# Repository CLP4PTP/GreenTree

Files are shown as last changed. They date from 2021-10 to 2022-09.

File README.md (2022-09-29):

Version 1.0: costs approx. 20 euros per tree, production work per tree approx. 3-4 hours
Used parts:
https://www.reichelt.de/my/1888149
Slide switch 3 positions: https://www.muekra.de/schiebeschalter.html
Feet (4x) https://www.horter-shop.de/de/self-adhesive-foot-m3/110-self-adhesive-foot-with-internal-thread-m3-4260404260011.html
9V batteries

For flashing, 150k resistors have turned out to be the best, as they flash at a pleasantly fast frequency.

Problems:
- Base board has already been changed to V2.0 (problem with transistor voltages have been fixed, but GND and VCC had to be swapped at the foot pins of the tree for this purpose) => LEDS must be soldered "wrong way around" on tree in version 1.0!
- Battery voltage drops from 9V to approx. 7V after a short period of operation. => Green, yellow and red LEDs go out very quickly because the voltage is too low
  Solution in V1.0: Bridge one LED per LED chain for green, yellow and red. Find a solution for this in the future or dimension the circuit correctly (e.g.buck converter to fixed voltage after battery)
- Extremely high soldering effort! Possible assembly e.g. from JLCPCB





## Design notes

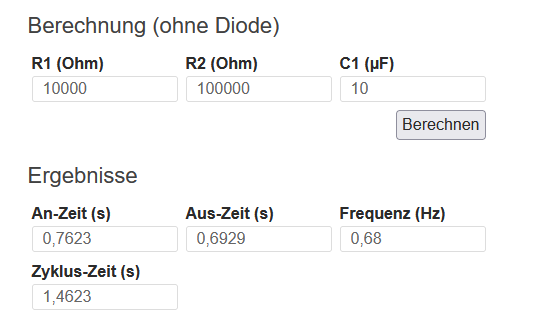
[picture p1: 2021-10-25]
NE555_1.PNG

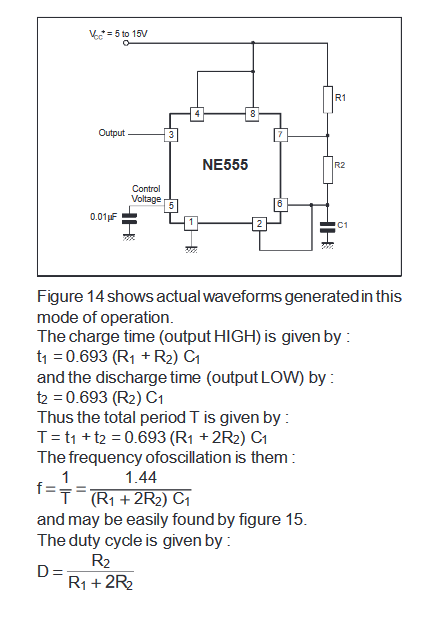
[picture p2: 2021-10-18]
NE555Beschaltung.PNG

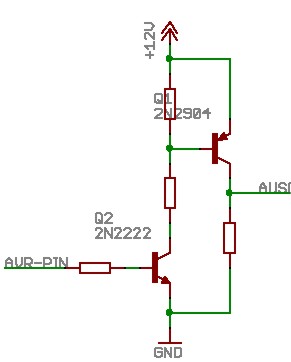
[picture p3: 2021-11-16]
KiCad_GreenTree/Base/Treiber.jpg

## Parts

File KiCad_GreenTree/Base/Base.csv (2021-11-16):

Source: | C:\Users\kbhan\OneDrive - student.kit.edu\Projekte\GreenTree\KiCad_GreenTree\Base\Base.sch
Date: | 15.11.2021 11:27:23
Tool: | Eeschema (5.1.8)-1
Component Count: | 36
Ref | Value | Footprint | Datasheet | Manufacturer | Vendor
BT3 | 9V | Bib:9V ohne Loecher | ~
C1 | 10n | Capacitor_SMD:C_0805_2012Metric_Pad1.18x1.45mm_HandSolder | ~
C2 | 10n | Capacitor_SMD:C_0805_2012Metric_Pad1.18x1.45mm_HandSolder | ~
C3 | C | Capacitor_SMD:C_0805_2012Metric_Pad1.18x1.45mm_HandSolder | ~
C4 | C | Capacitor_SMD:C_0805_2012Metric_Pad1.18x1.45mm_HandSolder | ~
C5 | 100n | Capacitor_SMD:C_0805_2012Metric_Pad1.18x1.45mm_HandSolder | ~
C6 | 100n | Capacitor_SMD:C_0805_2012Metric_Pad1.18x1.45mm_HandSolder | ~
C7 | Baum_Connector | Bib:Verbindung_Basis
C8 | 100n | Capacitor_SMD:C_0805_2012Metric_Pad1.18x1.45mm_HandSolder | ~
C9 | 330n | Capacitor_SMD:C_0805_2012Metric_Pad1.18x1.45mm_HandSolder | ~
C10 | 10n | Capacitor_SMD:C_0805_2012Metric_Pad1.18x1.45mm_HandSolder | ~
D1 | STPS 1L30A STM | Diode_SMD:D_SMA_Handsoldering | https://cdn-reichelt.de/documents/datenblatt/A400/STPS1L30X_ENG_TDS.pdf
D2 | STPS 1L30A STM | Diode_SMD:D_SMA_Handsoldering | https://cdn-reichelt.de/documents/datenblatt/A400/STPS1L30X_ENG_TDS.pdf
D3 | STPS 1L30A STM | Diode_SMD:D_SMA_Handsoldering | https://cdn-reichelt.de/documents/datenblatt/A400/STPS1L30X_ENG_TDS.pdf
D4 | STPS 1L30A STM | Diode_SMD:D_SMA_Handsoldering | https://cdn-reichelt.de/documents/datenblatt/A400/STPS1L30X_ENG_TDS.pdf
H1 | M3 | MountingHole:MountingHole_3.2mm_M3 | ~
H2 | M3 | MountingHole:MountingHole_3.2mm_M3 | ~
H3 | M3 | MountingHole:MountingHole_3.2mm_M3 | ~
H4 | M3 | MountingHole:MountingHole_3.2mm_M3 | ~
Q1 | BCX56 | Package_TO_SOT_SMD:SOT-89-3 | http://cache.nxp.com/documents/data_sheet/BCP56_BCX56_BC56PA.pdf?pspll=1
Q2 | BCX56 | Package_TO_SOT_SMD:SOT-89-3 | http://cache.nxp.com/documents/data_sheet/BCP56_BCX56_BC56PA.pdf?pspll=1
Q3 | BCX56 | Package_TO_SOT_SMD:SOT-89-3 | http://cache.nxp.com/documents/data_sheet/BCP56_BCX56_BC56PA.pdf?pspll=1
Q4 | BCX56 | Package_TO_SOT_SMD:SOT-89-3 | http://cache.nxp.com/documents/data_sheet/BCP56_BCX56_BC56PA.pdf?pspll=1
R1 | 10k | Resistor_SMD:R_0805_2012Metric_Pad1.20x1.40mm_HandSolder | ~
R2 | R | Resistor_SMD:R_0805_2012Metric_Pad1.20x1.40mm_HandSolder | ~
R3 | 10k | Resistor_SMD:R_0805_2012Metric_Pad1.20x1.40mm_HandSolder | ~
R4 | R | Resistor_SMD:R_0805_2012Metric_Pad1.20x1.40mm_HandSolder | ~
R5 | 1k | Resistor_SMD:R_1206_3216Metric_Pad1.30x1.75mm_HandSolder | ~
R6 | 1k | Resistor_SMD:R_1206_3216Metric_Pad1.30x1.75mm_HandSolder | ~
R7 | 1k | Resistor_SMD:R_0805_2012Metric_Pad1.20x1.40mm_HandSolder | ~
R8 | 1k | Resistor_SMD:R_0805_2012Metric_Pad1.20x1.40mm_HandSolder | ~
SW1 | SW_DPDT_x2 | Bib:Schiebeschalter
U1 | NE555D | Package_SO:SOIC-8_3.9x4.9mm_P1.27mm | http://www.ti.com/lit/ds/symlink/ne555.pdf
U2 | NE555D | Package_SO:SOIC-8_3.9x4.9mm_P1.27mm | http://www.ti.com/lit/ds/symlink/ne555.pdf
U3 | 74HC04 | Package_SO:SOIC-14W_7.5x9mm_P1.27mm | https://assets.nexperia.com/documents/data-sheet/74HC_HCT04.pdf
U4 | L78L05_TO92 | Package_TO_SOT_THT:TO-92_Inline | http://www.st.com/content/ccc/resource/technical/document/datasheet/15/55/e5/aa/23/5b/43/fd/CD00000446.pdf/files/CD00000446.pdf/jcr:content/translations/en.CD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

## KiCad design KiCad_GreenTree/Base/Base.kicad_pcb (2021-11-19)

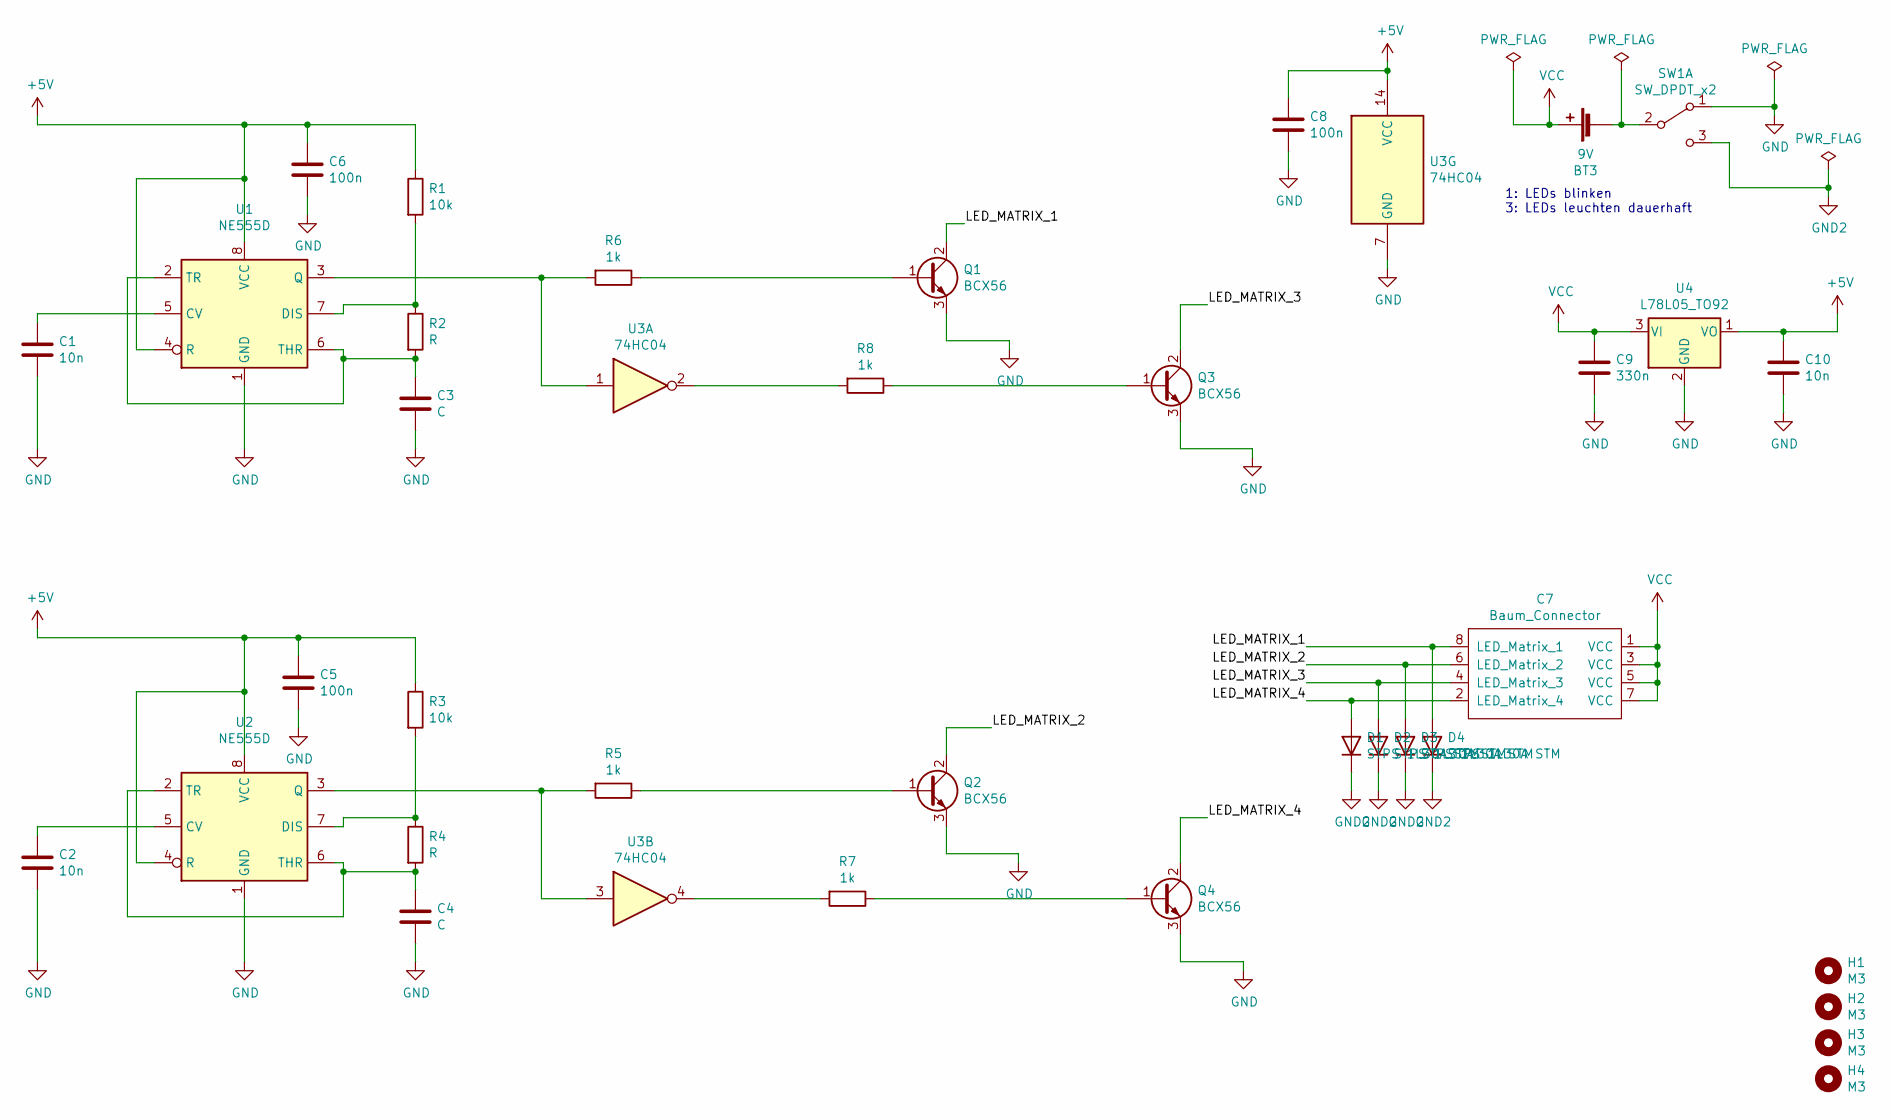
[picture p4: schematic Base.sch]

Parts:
BT3: 9V; 9V ohne Loecher
C1, C2, C10: 10n; C_0805_2012Metric_Pad1.18x1.45mm_HandSolder
C3, C4: C; C_0805_2012Metric_Pad1.18x1.45mm_HandSolder
C5, C6, C8: 100n; C_0805_2012Metric_Pad1.18x1.45mm_HandSolder
C7: Baum_Connector; Verbindung_Basis
C9: 330n; C_0805_2012Metric_Pad1.18x1.45mm_HandSolder
D1, D2, D3, D4: STPS 1L30A STM; D_SMA_Handsoldering
H1, H2, H3, H4: M3; MountingHole_3.2mm_M3
Q1, Q2, Q3, Q4: BCX56; SOT-89-3
R1, R3: 10k; R_0805_2012Metric_Pad1.20x1.40mm_HandSolder
R2, R4: R; R_0805_2012Metric_Pad1.20x1.40mm_HandSolder
R5, R6: 1k; R_1206_3216Metric_Pad1.30x1.75mm_HandSolder
R7, R8: 1k; R_0805_2012Metric_Pad1.20x1.40mm_HandSolder
SW1: SW_DPDT_x2; Schiebeschalter
U1, U2: NE555D; SOIC-8_3.9x4.9mm_P1.27mm
U3: 74HC04; SOIC-14_3.9x8.7mm_P1.27mm
U4: L78L05_TO92; TO-92_Inline

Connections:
+5V: C5.1, C6.1, C8.1, C10.1, R1.1, R3.1, U1.4 (R), U1.8 (VCC), U2.4 (R), U2.8 (VCC), U3.14 (VCC), U4.1 (VO)
/LED_MATRIX_1: C7.8 (LED_Matrix_1), D4.2 (A), Q1.2 (C)
/LED_MATRIX_2: C7.6 (LED_Matrix_2), D3.2 (A), Q2.2 (C)
/LED_MATRIX_3: C7.4 (LED_Matrix_3), D2.2 (A), Q3.2 (C)
/LED_MATRIX_4: C7.2 (LED_Matrix_4), D1.2 (A), Q4.2 (C)
GND: C1.2, C2.2, C3.2, C4.2, C5.2, C6.2, C8.2, C9.2, C10.2, Q1.3 (E), Q2.3 (E), Q3.3 (E), Q4.3 (E), SW1.1 (A), U1.1 (GND), U2.1 (GND), U3.7 (GND), U4.2 (GND)
GND2: D1.1 (K), D2.1 (K), D3.1 (K), D4.1 (K), SW1.3 (C)
unnamed: BT3.2 (-), SW1.2 (B)
unnamed: C1.1, U1.5 (CV)
unnamed: C2.1, U2.5 (CV)
unnamed: C3.1, R2.2, U1.2 (TR), U1.6 (THR)
unnamed: C4.1, R4.2, U2.2 (TR), U2.6 (THR)
unnamed: Q1.1 (B), R6.1
unnamed: Q2.1 (B), R5.1
unnamed: Q3.1 (B), R8.1
unnamed: Q4.1 (B), R7.1
unnamed: R1.2, R2.1, U1.7 (DIS)
unnamed: R3.2, R4.1, U2.7 (DIS)
unnamed: R5.2, U2.3 (Q), U3.3
unnamed: R6.2, U1.3 (Q), U3.1
unnamed: R7.2, U3.4
unnamed: R8.2, U3.2
VCC: BT3.1 (+), C7.1 (VCC), C7.3 (VCC), C7.5 (VCC), C7.7 (VCC), C9.1, U4.3 (VI)

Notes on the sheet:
1: LEDs blinken 3: LEDs leuchten dauerhaft

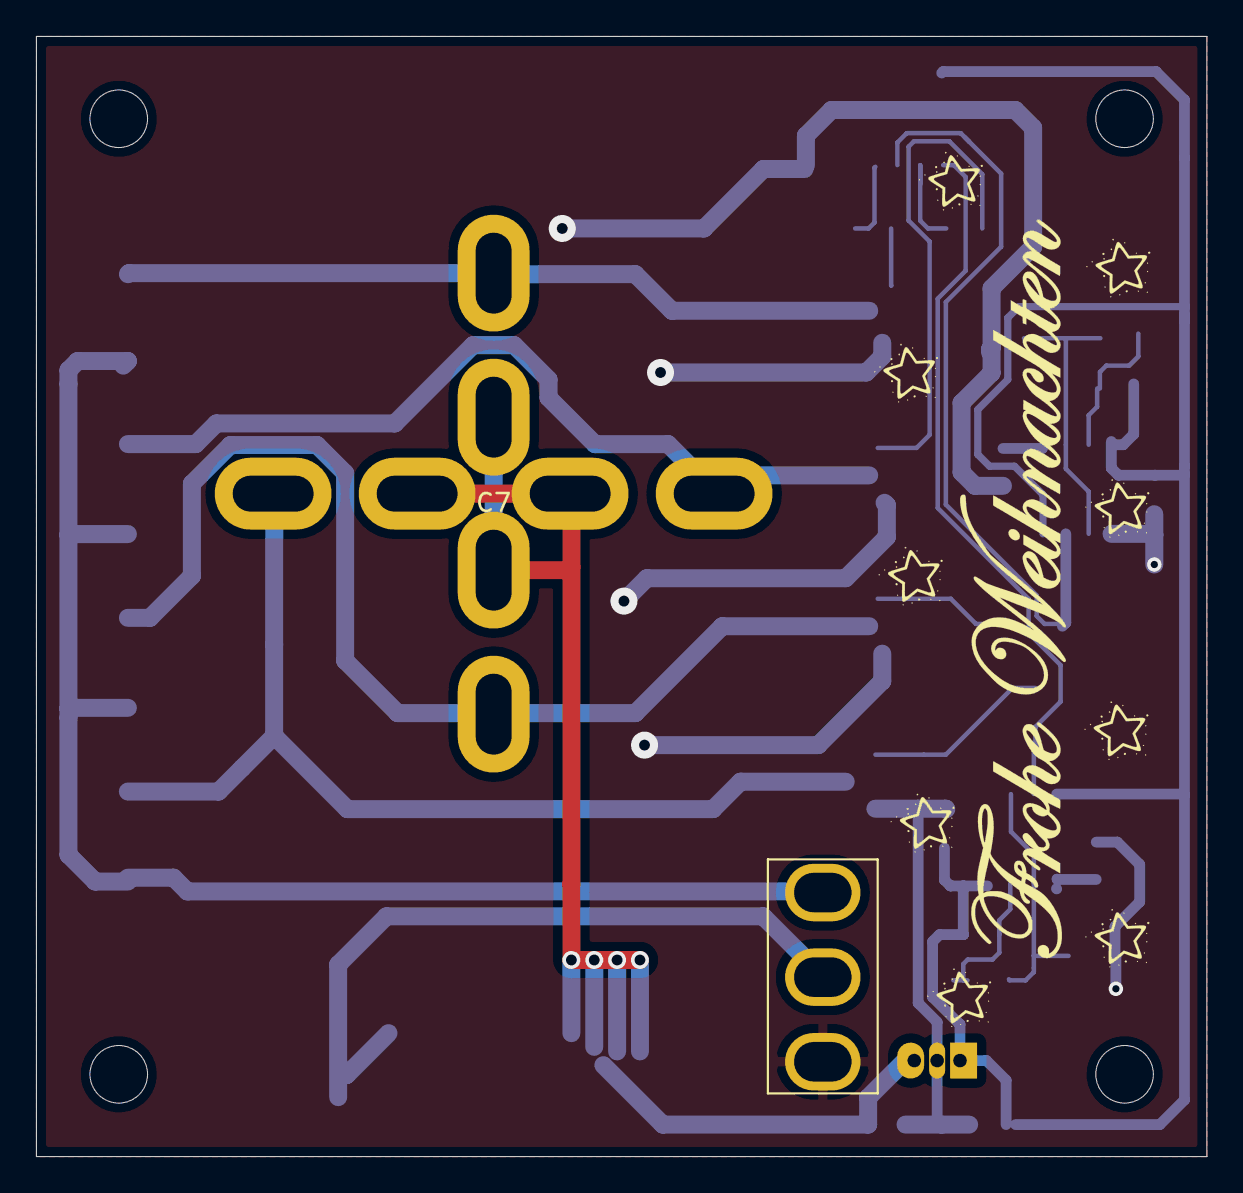
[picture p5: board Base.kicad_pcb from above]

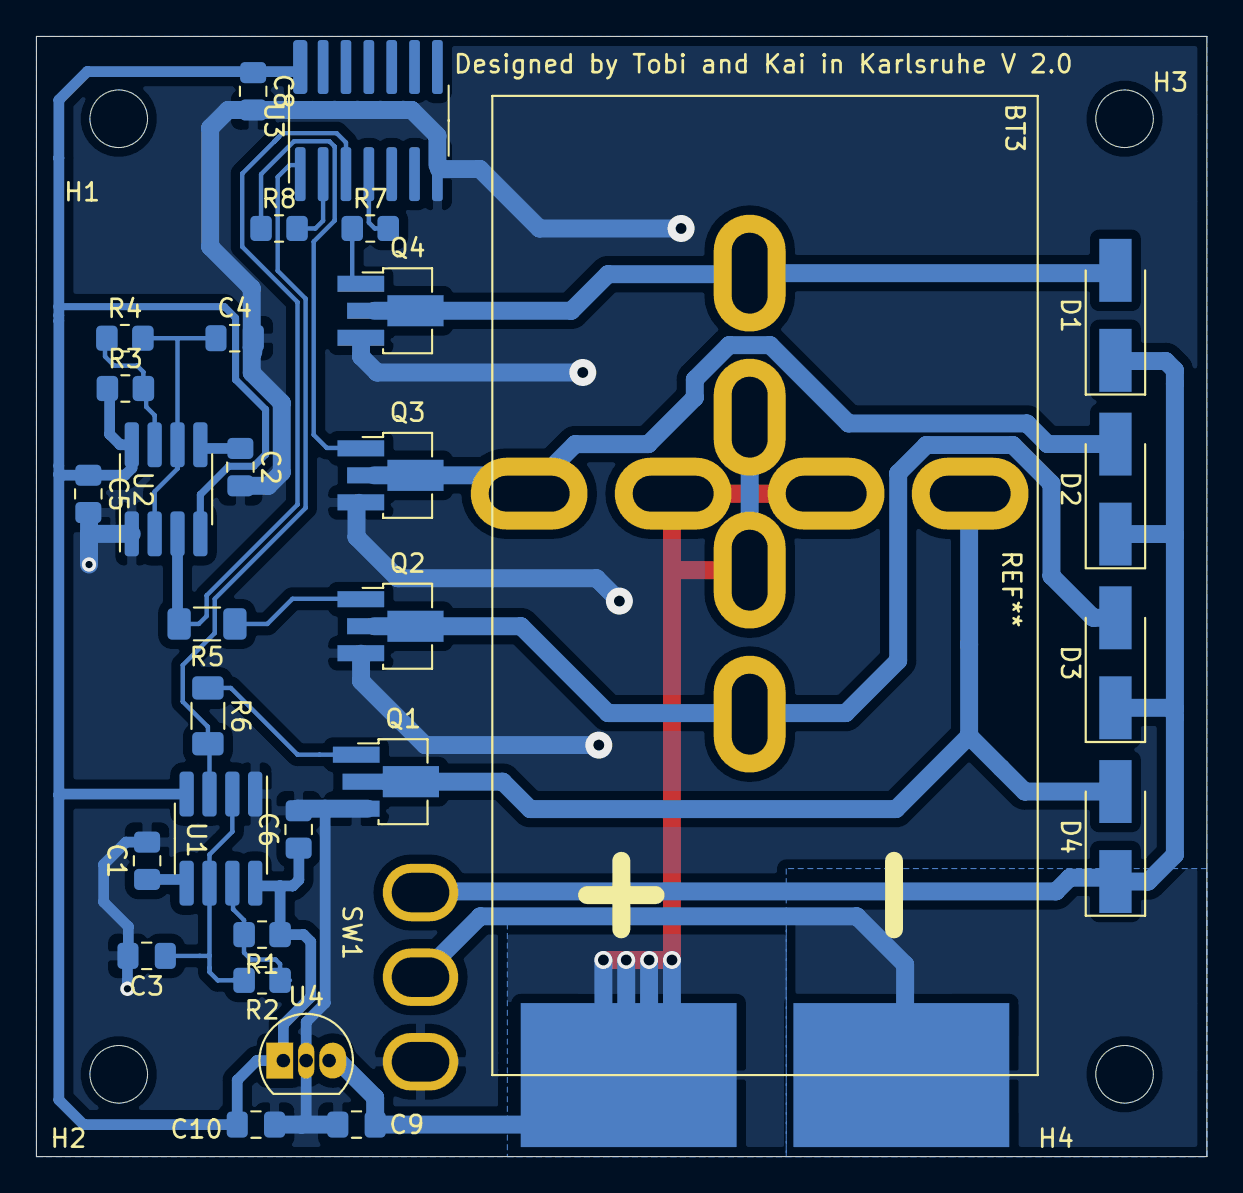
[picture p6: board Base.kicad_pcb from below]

Board: 2 copper layers, 65.0 x 62.2 mm, 36 parts (30 on the bottom side), 23 nets.

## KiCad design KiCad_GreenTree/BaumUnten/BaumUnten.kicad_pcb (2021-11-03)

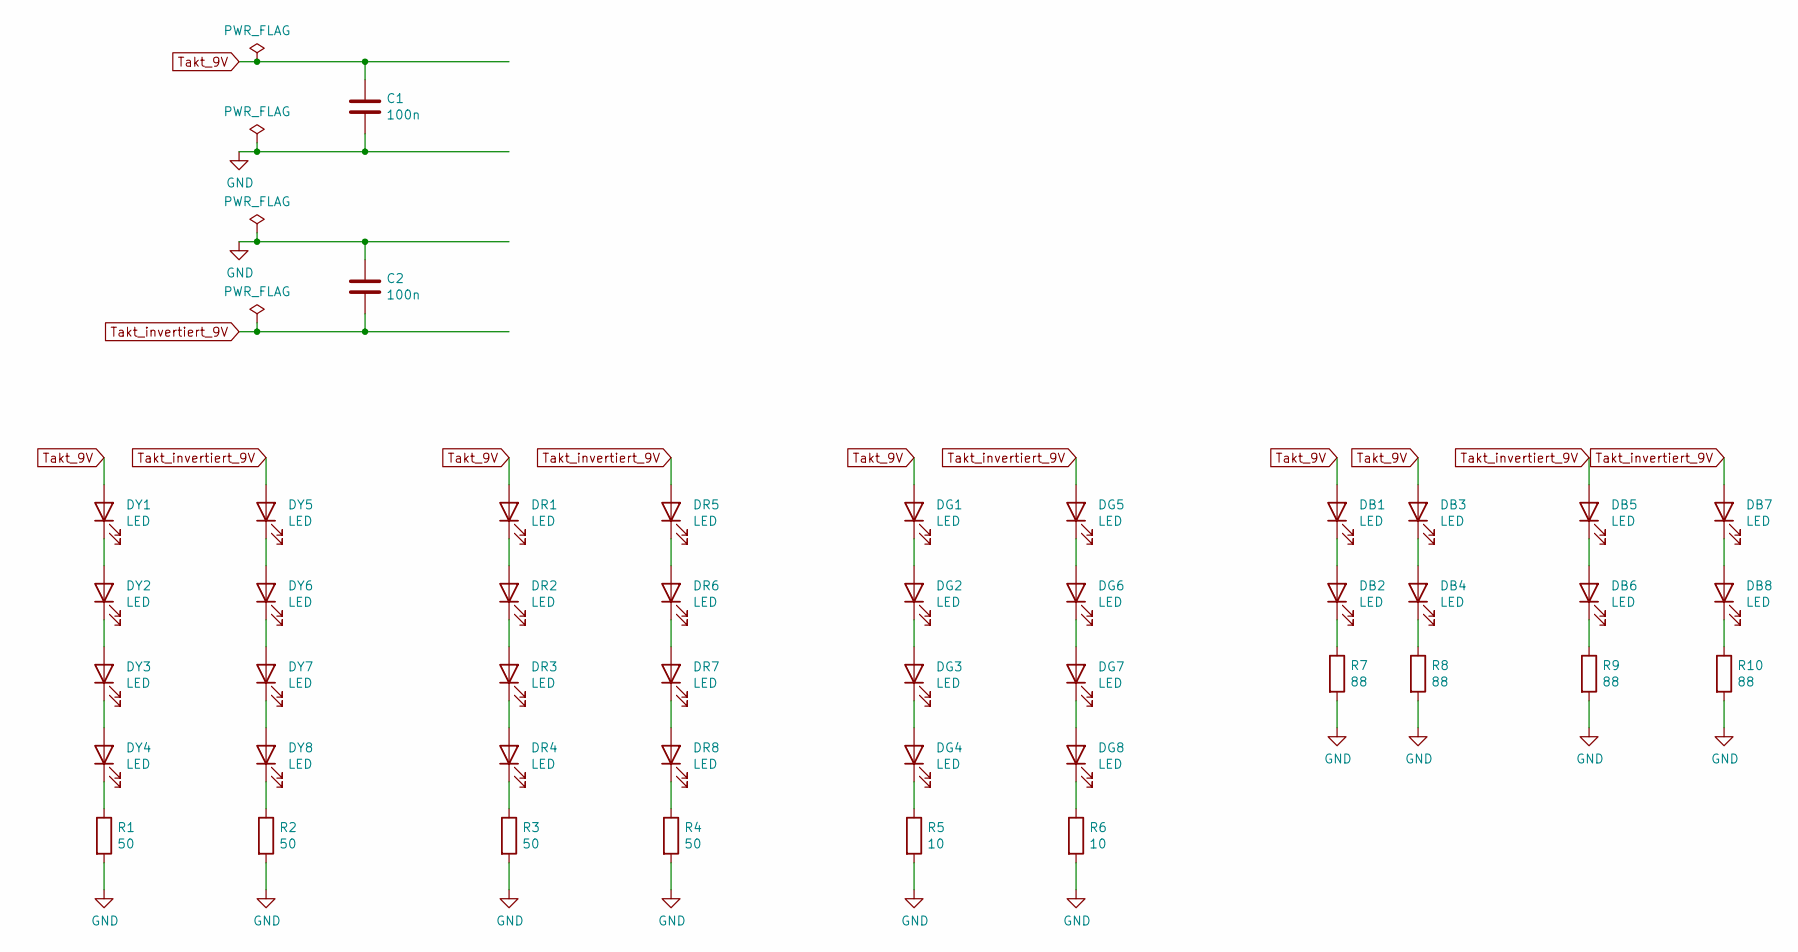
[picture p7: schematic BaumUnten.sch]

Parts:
C1, C2: 100n; C_0805_2012Metric_Pad1.15x1.40mm_HandSolder
DB1, DB2, DB3, DB4, DB5, DB6, DB7, DB8: LED; D_0603_1608Metric_Pad1.05x0.95mm_HandSolder
DG1, DG2, DG3, DG4, DG5, DG6, DG7, DG8: LED; D_0805_2012Metric_Pad1.15x1.40mm_HandSolder
DR1, DR2, DR3, DR4, DR5, DR6, DR7, DR8: LED; D_0805_2012Metric_Pad1.15x1.40mm_HandSolder
DY1, DY2, DY3, DY4, DY5, DY6, DY7, DY8: LED; D_0805_2012Metric_Pad1.15x1.40mm_HandSolder
R1, R2, R3, R4: 50; R_0805_2012Metric_Pad1.15x1.40mm_HandSolder
R5, R6: 10; R_0805_2012Metric_Pad1.15x1.40mm_HandSolder
R7, R8, R9, R10: 88; R_0805_2012Metric_Pad1.15x1.40mm_HandSolder

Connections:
GND: C1.2, C2.1, R1.2, R2.2, R3.2, R4.2, R5.2, R6.2, R7.2, R8.2, R9.2, R10.2
unnamed: DB1.1 (K), DB2.2 (A)
unnamed: DB2.1 (K), R7.1
unnamed: DB3.1 (K), DB4.2 (A)
unnamed: DB4.1 (K), R8.1
unnamed: DB5.1 (K), DB6.2 (A)
unnamed: DB6.1 (K), R9.1
unnamed: DB7.1 (K), DB8.2 (A)
unnamed: DB8.1 (K), R10.1
unnamed: DG1.1 (K), DG2.2 (A)
unnamed: DG2.1 (K), DG3.2 (A)
unnamed: DG3.1 (K), DG4.2 (A)
unnamed: DG4.1 (K), R5.1
unnamed: DG5.1 (K), DG6.2 (A)
unnamed: DG6.1 (K), DG7.2 (A)
unnamed: DG7.1 (K), DG8.2 (A)
unnamed: DG8.1 (K), R6.1
unnamed: DR1.1 (K), DR2.2 (A)
unnamed: DR2.1 (K), DR3.2 (A)
unnamed: DR3.1 (K), DR4.2 (A)
unnamed: DR4.1 (K), R3.1
unnamed: DR5.1 (K), DR6.2 (A)
unnamed: DR6.1 (K), DR7.2 (A)
unnamed: DR7.1 (K), DR8.2 (A)
unnamed: DR8.1 (K), R4.1
unnamed: DY1.1 (K), DY2.2 (A)
unnamed: DY2.1 (K), DY3.2 (A)
unnamed: DY3.1 (K), DY4.2 (A)
unnamed: DY4.1 (K), R1.1
unnamed: DY5.1 (K), DY6.2 (A)
unnamed: DY6.1 (K), DY7.2 (A)
unnamed: DY7.1 (K), DY8.2 (A)
unnamed: DY8.1 (K), R2.1
Takt_9V: C1.1, DB1.2 (A), DB3.2 (A), DG1.2 (A), DR1.2 (A), DY1.2 (A)
Takt_invertiert_9V: C2.2, DB5.2 (A), DB7.2 (A), DG5.2 (A), DR5.2 (A), DY5.2 (A)

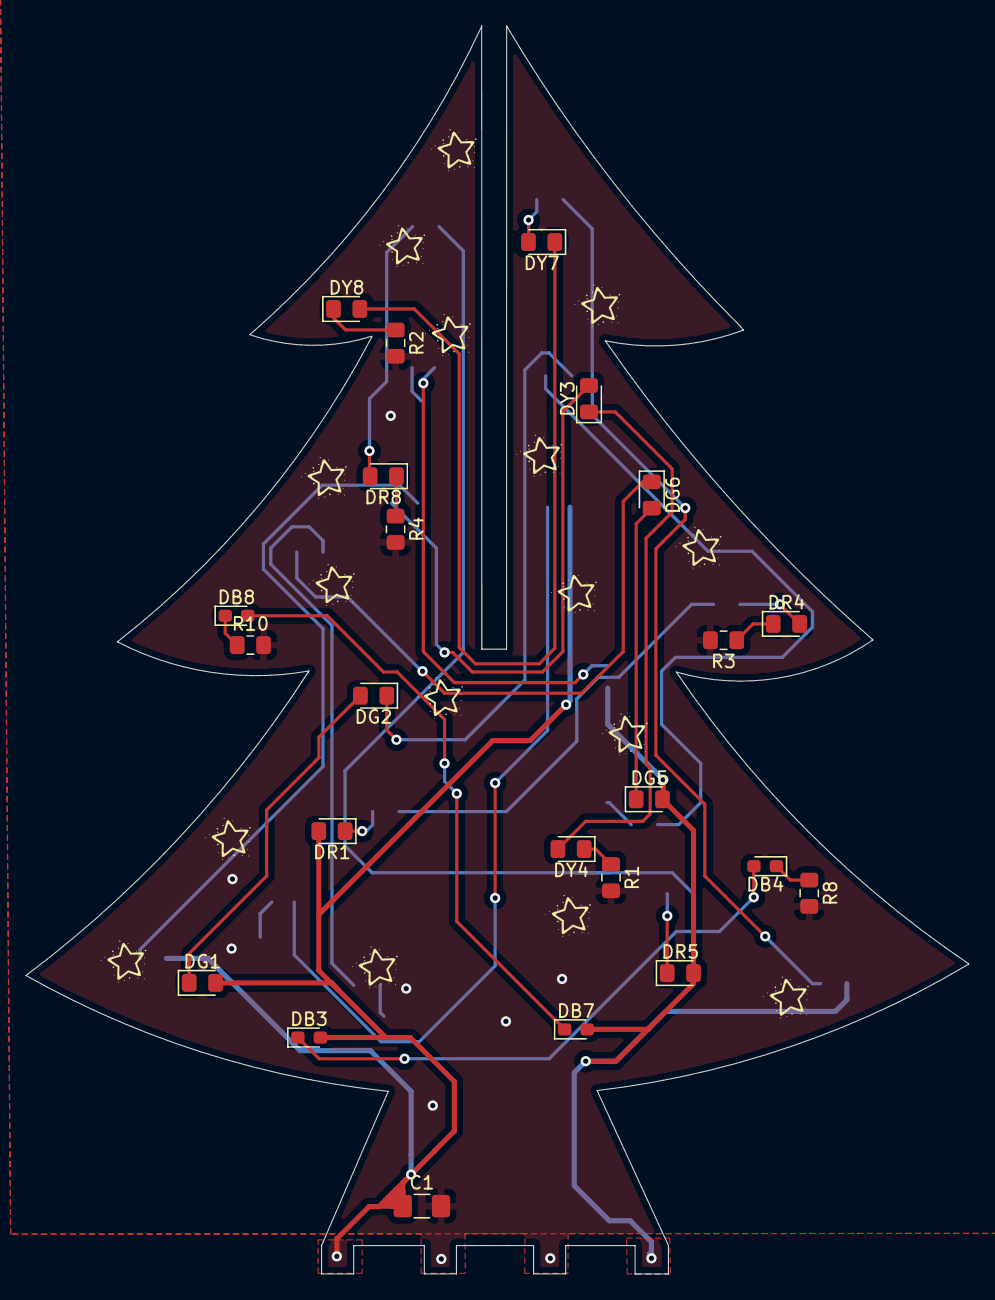
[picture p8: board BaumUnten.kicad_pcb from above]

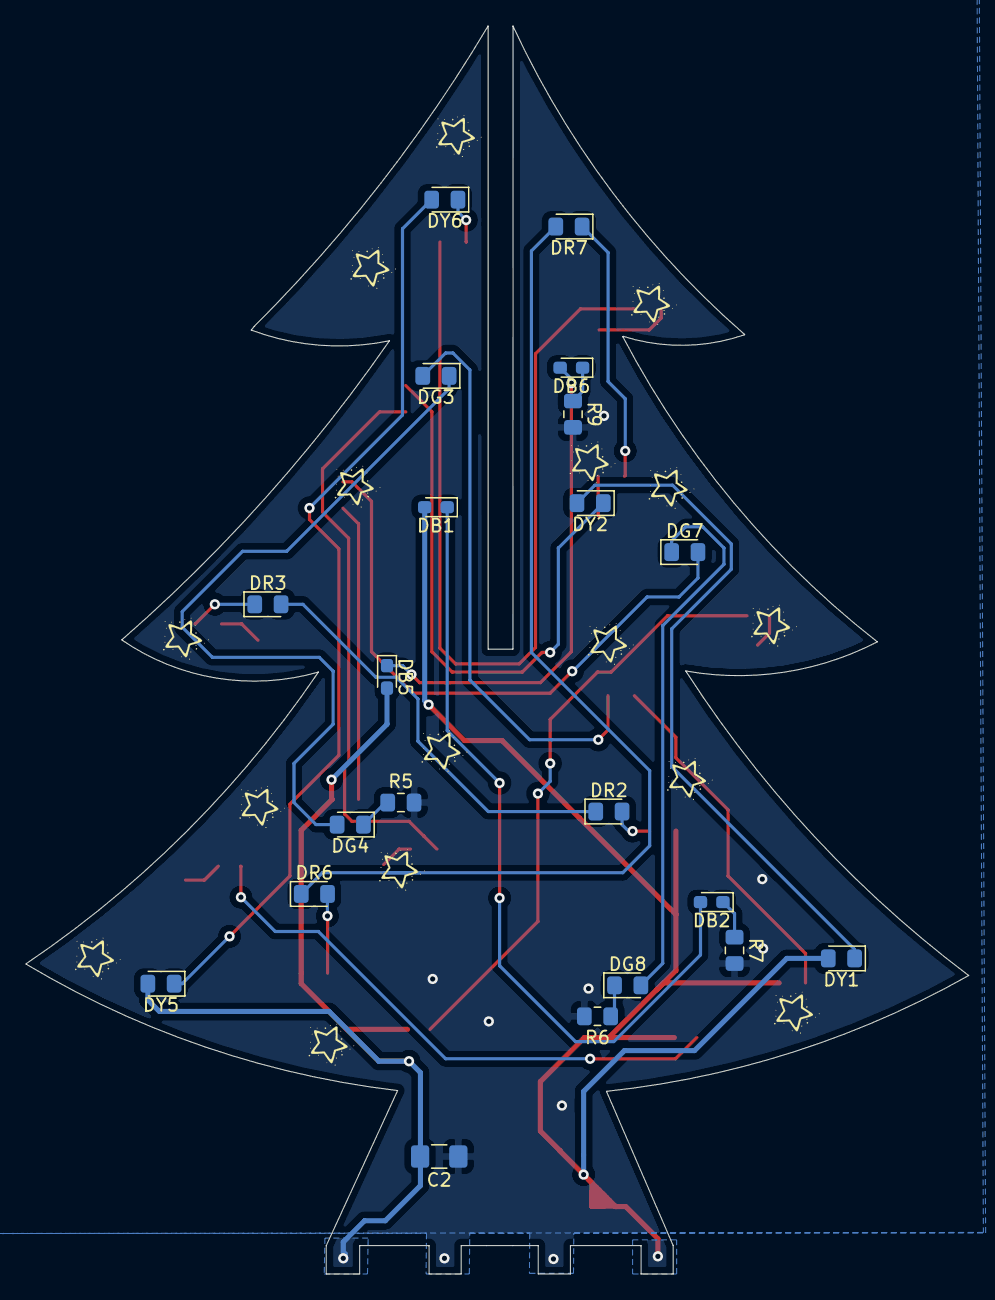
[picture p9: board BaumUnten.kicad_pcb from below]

Board: 2 copper layers, 73.4 x 97.1 mm, 44 parts (21 on the bottom side), 35 nets.

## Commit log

2021-10-15 init Kicad
    [KiCad_GreenTree.kicad_pcb, KiCad_GreenTree.sch]
2021-10-17 Baum oben pcb outline fertig
    [BaumOben.kicad_pcb, BaumOben.sch]
2021-10-17 some work on Base
    [Base.kicad_pcb]
2021-10-17 Verbindung zu Baum
    [Base.kicad_pcb, Base.sch]
2021-10-17 NE555 Layout
    [Base.kicad_pcb, Base.sch]
2021-10-18 Without GND
    [Base.kicad_pcb]
2021-10-18 Schaltplan oben
    Schaltplan oben fertig und Layout angefangen
    [BaumOben.sch]
2021-10-19 gerber kaputt
2021-10-19 fixed Edge Cuts
    [Base.kicad_pcb]
2021-10-19 baum unten sachen kopiert
    [BaumUnten.kicad_pcb, BaumUnten.sch]
2021-10-20 ordentlicher Schaltplan
    NO DRC errors anymore
    [Base.kicad_pcb, Base.sch]
2021-10-20 Added Diodes
    [Base.kicad_pcb, Base.sch]
2021-10-20 fixed Diodes
    [Base-B_Cu.gbr, Base-B_Mask.gbr, Base-B_Paste.gbr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]
2021-10-20 added 5V
    [Base.kicad_pcb, Base.sch]
2021-10-20 fixed Inv
    [Base.kicad_pcb, Base.sch]
2021-10-20 bis auf silk fertig
    baum unten fertig gemacht und Beinchen gekürzt
2021-10-23 sterne auf silkscreen baum
    [BaumUnten.kicad_pcb]
2021-10-24 Schlitz korrigiert und Schrift Base
    [BaumUnten.kicad_pcb, design_versuch_base.kicad_pcb]
2021-10-25 optimierung der Leitungen
    [design_versuch_base.kicad_pcb]
2021-10-27 edgecuts angepasst
    [BaumUnten-B_Cu.gbr, BaumUnten-B_Mask.gbr, BaumUnten-B_Paste.gbr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]
2021-10-27 footprint auf 0805
    [BaumUnten-B_Cu.gbr, BaumUnten-B_Mask.gbr, BaumUnten-B_Paste.gbr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]
2021-11-16 nothing works
    Transistoren gegen GND schalten
    Footprint Inverter und Schalter ändern
    Inverter Spannungslevel anpassen. (Schalten der Transistoren beachten)
    SMD linearregler?
    Größere Widerstande bestellen
    Andere Füße
    [Base.csv, Base.kicad_pcb, Base.sch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]
2021-11-17 Base V2.0
    Finished Rework. Sould now work. Hoping for the best
    [Base.kicad_pcb, Base.sch]
2021-11-18 V 2.0
    [Base-B_Cu.gbr, Base-B_Mask.gbr, Base-B_Paste.gbr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]
2021-11-19 Order JLCPCB
    [Base-B_Cu.gbl, Base-B_Mask.gbs, Base-B_Paste.gbp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]
2021-11-19 Replacmentfile JLC
    fixed bug where outline of Switch was Sodermask insted of silkscreen
    [Base-B_Cu.gbl, Base-B_Mask.gbs, Base-B_Paste.gbp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]
